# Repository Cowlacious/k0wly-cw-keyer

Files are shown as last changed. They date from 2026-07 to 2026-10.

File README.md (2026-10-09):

# K0WLY Two-Way CW Keyer






A full-featured two-way CW (Morse code) keyer built on the LilyGO T-Display S3 AMOLED board, featuring peer-to-peer WiFi communication via ESP-NOW, real-time Morse decoding, and a beautiful 1.91" AMOLED display.

**Designed and built by K0WLY — Saratoga Springs, Utah — Grid DN40**

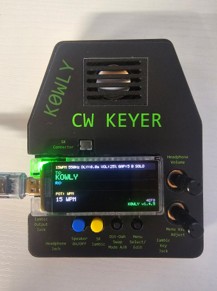
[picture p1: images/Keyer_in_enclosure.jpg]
K0WLY CW Keyer — Top View
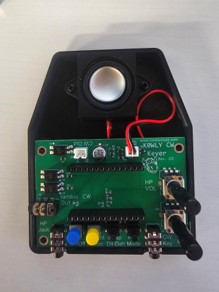
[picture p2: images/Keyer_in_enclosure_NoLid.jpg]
K0WLY CW Keyer — System View
  
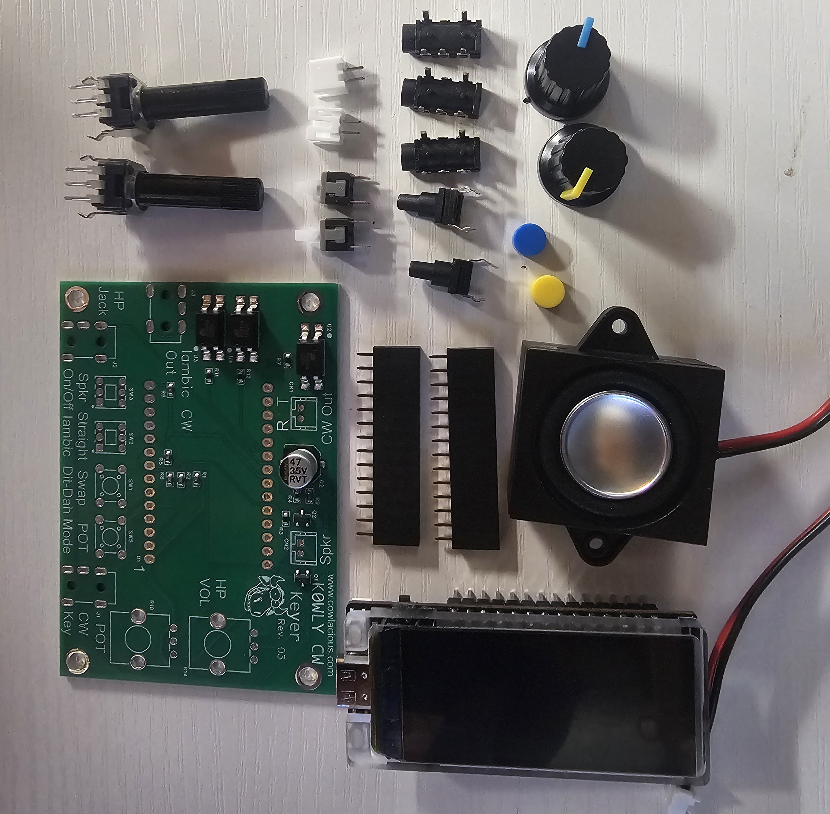
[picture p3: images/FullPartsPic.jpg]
K0WLY CW Keyer — Parts View


---

## Features

- **Iambic Mode A, Iambic Mode B and Ultimatic keyer modes** with adjustable speed (5–40 WPM)
- **Straight key mode** selectable via hardware switch
- **Adjustable sidetone frequency** (400–900 Hz) — each unit independent
- **Logarithmic volume control** via PWM, works for speaker and headphones
- **Head copy delay** (0–3 seconds) for incoming character display
- **WiFi file playback** — upload .txt practice files from any phone browser, plays as CW
- **WiFi Access Point** — unique hotspot per unit (K0WLY-XXXX), no password, works on all platforms
- **Iambic DIT/DAH output** (GPIO40/41) — connect to radio paddle input for radios with built-in keyers (e.g. Xiegu G90)
- **Web interface** — dit/dah swap, file management, all from phone browser at 192.168.4.1
- **Automatic peer-to-peer WiFi pairing** via ESP-NOW — no router needed
- **Two-way CW communication** — transmit and receive simultaneously
- **Real-time Morse decoding** — letters, numbers, punctuation, and prosigns
- **Scrolling TX/RX display** on 1.91" AMOLED (536×240)
- **Farnsworth spacing** — two-speed CW for learning (character speed plus a 4 WPM-or-higher overall speed, e.g. 20/10)
- **Adjustable word gap spacing** (off or 4–9 dits) for display readability
- **Non-volatile settings** — survives power cycles
- **Single pot** with mode cycling for all parameter adjustments
- **Frame buffer display** — instantaneous screen updates, no glitch

---

## Hardware

### Bill of Materials

| Component | Value | Notes |
|---|---|---|
| MCU Board | LilyGO T-Display S3 AMOLED | ESP32-S3R8, 1.91" AMOLED |
| Optocoupler | PC817 | Radio key line isolation |
| Transistors | 2N4401 × 2 | Speaker + headphone audio |
| Base resistors | 470Ω × 2 | GPIO13 to transistor bases |
| Pull-up resistors | 10kΩ × 2 | DIT/DAH paddle inputs |
| Key mode resistor | 100kΩ | GPIO15 pull-up |
| Headphone pull-up | 1kΩ | Headphone transistor collector |
| Coupling cap | 47µF bi-polar | Headphone output only |
| Headphone resistor | 100Ω | Series protection |
| Pot | 10–20kΩ linear | Parameter adjustment |
| Speaker | 8Ω | Direct connection, no cap needed |
| 3.5mm jack | TRS | Headphone output |

### GPIO Pin Assignments

| Function | GPIO | Notes |
|---|---|---|
| DIT Paddle | GPIO11 | Active LOW, ext 10kΩ pull-up |
| DAH Paddle | GPIO10 | Active LOW, ext 10kΩ pull-up |
| Key Out | GPIO12 | HIGH=keyed, drives PC817 |
| Sidetone | GPIO13 | PWM → 470Ω → 2N4401 |
| Pot (ADC) | GPIO14 | Wiper of 10–20kΩ pot |
| Key Mode | GPIO15 | SPST: open=iambic, GND=straight key |
| Paddle Reverse | GPIO16 | PBNO momentary button — short press swaps dit/dah, long press (1 sec) cycles keyer mode A → B → U (Ultimatic) |
| Pot Mode Select | GPIO39 | PBNO momentary button |

### Audio Circuit Notes

**Speaker circuit** — direct connection, no coupling capacitor:
```
3.3V ──── Speaker ──── Collector
                           │
GPIO13 ── 470Ω ── Base  2N4401 #1
                           │
                       Emitter ──── GND
```

**Headphone circuit** — separate transistor with coupling cap:
```
3.3V ──── 1kΩ ──── Collector
                       │
                   +47µF- ──── 100Ω ──── 3.5mm tip
                       │                 3.5mm sleeve ──── GND
GPIO13 ── 470Ω ── Base  2N4401 #2
                           │
                       Emitter ──── GND
```

> **Note:** The speaker connects directly without a coupling capacitor. A coupling cap in series with the speaker will block all audio. The headphone output uses a separate transistor with its own 3.3V pull-up and a 47µF bi-polar coupling cap to block DC.

---

## Firmware

### Requirements

- [PlatformIO](https://platformio.org/) with VS Code
- ESP32 Arduino framework 2.0.x

### platformio.ini

This is the project's `firmware/platformio.ini`. It uses the custom board definition in `firmware/boards/` and the partition table in `firmware/partitions.csv`.

```ini
[platformio]
boards_dir = ./boards

[env:t_display_s3_amoled]
platform = espressif32
board = lilygo-t-amoled
framework = arduino
monitor_speed = 115200
board_build.partitions = partitions.csv
board_build.filesystem = littlefs
build_flags =
    -DBOARD_HAS_PSRAM
    -DARDUINO_USB_CDC_ON_BOOT=1
    -DASYNCWEBSERVER_REGEX=0
lib_deps =
    https://github.com/Xinyuan-LilyGO/LilyGo-AMOLED-Series
    https://github.com/moononournation/Arduino_GFX#v1.4.7
    https://github.com/ESP32Async/AsyncTCP
    https://github.com/ESP32Async/ESPAsyncWebServer
```

### Building and Flashing

1. Clone this repository
2. Open the `firmware/` folder in VS Code with PlatformIO
3. Connect the T-Display S3 AMOLED via USB
4. Hold BOOT button, plug in USB, release BOOT
5. Click Upload in PlatformIO

---

## Operation

### Display Layout

```
┌─────────────────────────────────────────────────────────────────────┐
│ K0WLY   20WPM  700Hz  DLY:0.0s  VOL:50%       IAM  SOLO           │  ← Header
├─────────────────────────────────────────────────────────────────────┤
│ TX> CQ CQ CQ DE K0WLY K0WLY K                                      │  ← Outgoing (green)
├─────────────────────────────────────────────────────────────────────┤
│ RX> TNX FER CALL OM 73 DE                                           │  ← Incoming (cyan)
├─────────────────────────────────────────────────────────────────────┤
│ POT: WPM                                                            │
│ 20 WPM                                                              │  ← Status area
│ SEARCHING...                                                        │
└─────────────────────────────────────────────────────────────────────┘
```

### Parameter Adjustment

| Button Action | Result |
|---|---|
| Short press | Cycle to next parameter: WPM → FREQ → DELAY → VOL |
| Long press (1 sec) | Enter/exit edit mode for current parameter |
| Turn pot (in edit) | Adjust value — saves to flash in real time |

### Two-Way Operation

1. Power on both units — they auto-discover each other via ESP-NOW
2. Header changes from **SOLO** to **DUAL** when paired
3. Each unit hears all CW at its own sidetone frequency
4. Incoming decoded characters appear on the RX line (cyan)
5. Head copy delay (0–3s) lets you practice mental decoding

### Morse Code Coverage

Letters A–Z, numbers 0–9, punctuation (. , ? / ( ) : ; - ' " @ & ! _),
and prosigns: **+** = AR, **=** = BT, **~** = SK

---

## CW Timing Standard

**PARIS standard (ITU-R M.1677-1)**

| Element | Duration |
|---|---|
| Dit | 1 × (1200/WPM) ms |
| Dah | 3 × (1200/WPM) ms |
| Inter-element gap | 1 × (1200/WPM) ms |
| Character gap | 3 × (1200/WPM) ms |
| Word gap | 7 × (1200/WPM) ms |

---

## Updating Firmware

Each GitHub release includes a pre-compiled `firmware.bin` file that can be flashed without installing PlatformIO or compiling any code.

### Option 1 — Espressif Flash Download Tool (Windows, easiest)

1. Download the **[Espressif Flash Download Tool](https://www.espressif.com/en/support/download/other-tools)** — look for "Flash Download Tools" and download the `.zip`
2. Extract and run `flash_download_tool.exe`
3. Select **ESP32-S3** as the chip type
4. Click the `...` button next to the first address field and select your `firmware.bin`
5. Set the address to `0x10000`
6. Select your COM port from the dropdown (check Device Manager if unsure)
7. Set baud rate to `921600`
8. Click **START**
9. If it fails to connect, hold the **BOOT** button on the board, press and release **RST**, then release **BOOT** and click START again

### Option 2 — esptool.py (Windows / Mac / Linux)

**Install esptool** (requires Python):
```
pip install esptool
```

**Flash the firmware:**
```
esptool.py --port COM3 --baud 921600 write_flash 0x10000 firmware.bin
```

Replace `COM3` with your actual port:
- **Windows** — check Device Manager under Ports (COM & LPT)
- **Mac** — typically `/dev/tty.usbmodem101` or `/dev/cu.usbmodem101`
- **Linux** — typically `/dev/ttyACM0`

If connection fails, hold **BOOT**, press **RST**, release **BOOT**, then run the command.

### Building from Source

For developers who want to modify the firmware:
- Install [VS Code](https://code.visualstudio.com/) and the [PlatformIO extension](https://platformio.org/)
- Clone this repository
- Open `firmware/` folder in VS Code
- The `lilygo-t-amoled` board definition (`firmware/boards/lilygo-t-amoled.json`) and partition table (`firmware/partitions.csv`) are already included
- Build and upload using PlatformIO

---
## Repository Structure

```
k0wly-cw-keyer/
├── firmware/          # PlatformIO project
│   ├── src/
│   │   └── main.cpp
│   ├── boards/        # lilygo-t-amoled board definition
│   ├── partitions.csv
│   └── platformio.ini
├── hardware/
│   ├── schematic/     # Schematic PDFs and BOMs
│   ├── pcb/           # Gerbers and pick-and-place files
│   └── enclosure/     # Enclosure 3D models (SolidWorks and STL)
├── docs/              # Operator's Manual (DOCX and PDF) and User Guide (DOCX)
├── images/            # Photos and screenshots
├── LICENSE            # CERN-OHL-W v2 (hardware + firmware)
├── LICENSE-DOCS       # CC BY 4.0 (documentation)
├── NOTICE             # Required attribution notice
├── CONTRIBUTING.md
├── CHANGELOG.md
└── README.md
```

---

## License

**Hardware and Firmware:** Licensed under the
[CERN Open Hardware Licence Version 2 - Weakly Reciprocal (CERN-OHL-W v2)](LICENSE).

**Documentation:** Licensed under
[Creative Commons Attribution 4.0 International (CC BY 4.0)](LICENSE-DOCS).

Copyright © 2026 K0WLY (Carl Cowley) — Saratoga Springs, Utah

Attribution to **K0WLY** must be retained on all copies and derivatives.

---

## Contributing

See [CONTRIBUTING.md](CONTRIBUTING.md) for guidelines.

## Changelog

See [CHANGELOG.md](CHANGELOG.md) for version history.

---

*73 de K0WLY — dit dit*

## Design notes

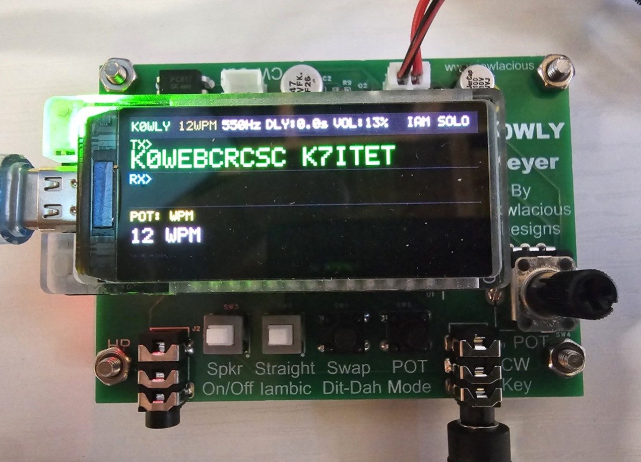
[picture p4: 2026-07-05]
images/keyer_top.jpg

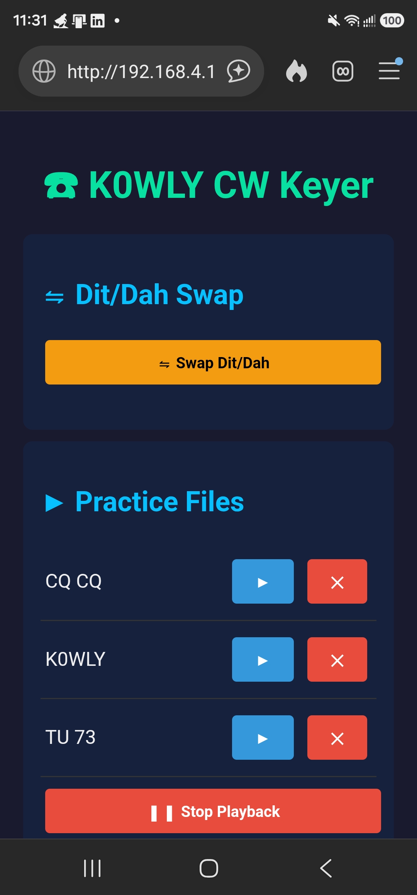
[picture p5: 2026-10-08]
images/Screenshot1_WebPage.jpg

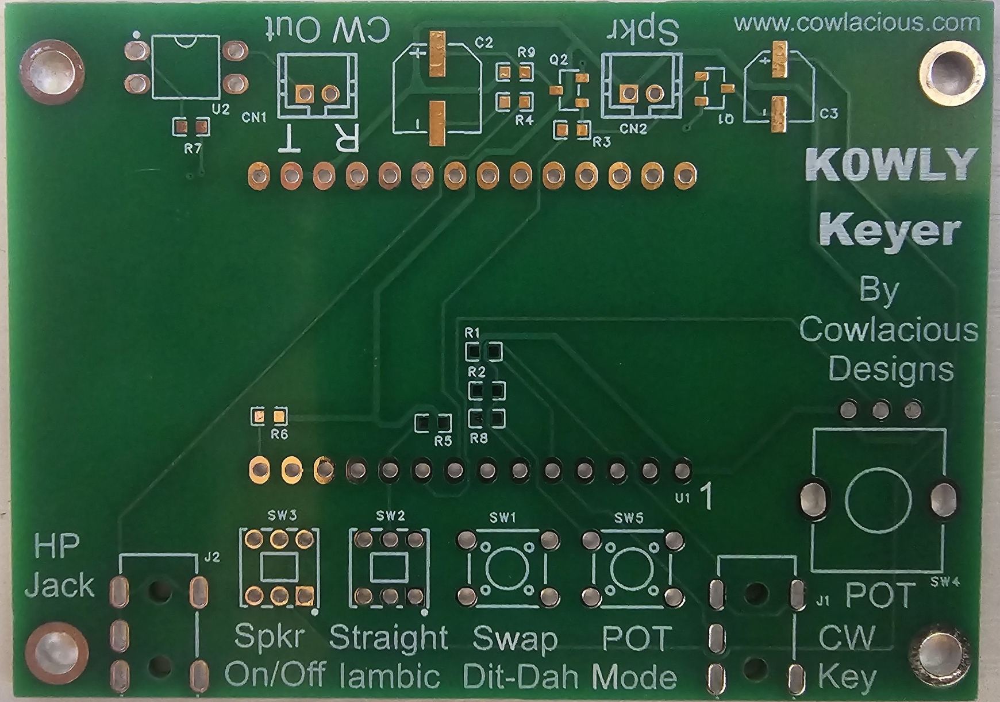
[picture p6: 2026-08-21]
images/Keyer_PCB.jpg

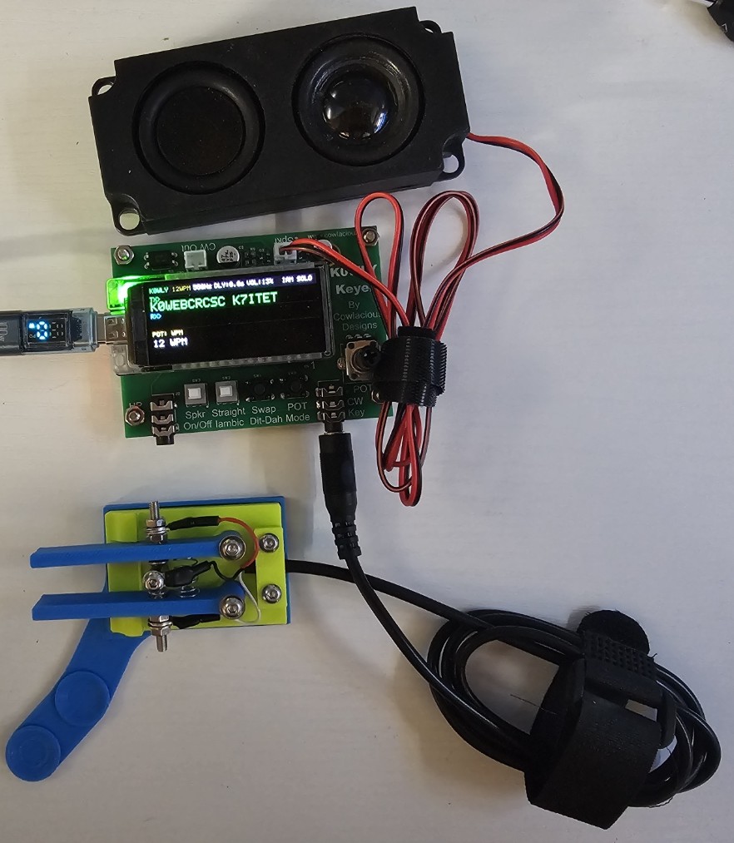
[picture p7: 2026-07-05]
images/keyer_system.jpg

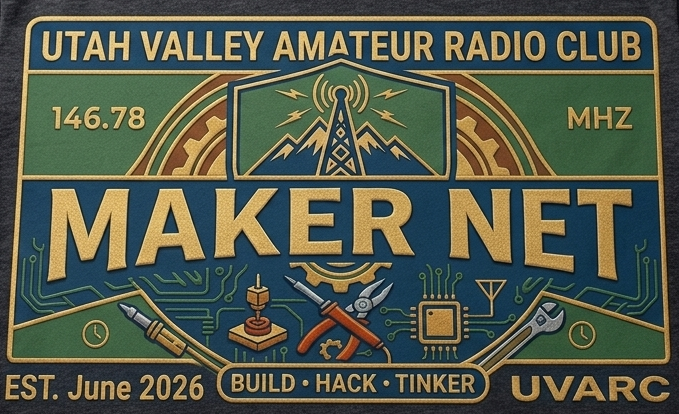
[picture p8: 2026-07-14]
images/Gemini_Generated_Image_x44wqgx44wqgx44w (1).png

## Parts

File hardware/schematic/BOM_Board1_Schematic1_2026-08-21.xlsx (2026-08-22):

No. | Quantity | Comment | Designator | Footprint | Value | Manufacturer Part | Manufacturer | Supplier Part | Supplier
1 | 1 | 47uF | C2 | CAP-SMD_BD6.3-L6.6-W6.6-FD | 47uF | RVT1V470M0605 | ROQANG(容强) | C72522 | LCSC
2 | 2 | PH-2A | CN1,CN2 | CONN-TH_PH-2A_C53055425 |  | PH-2A | LXWCONN(连兴旺电子) | C53055425 | LCSC
3 | 3 | 313耳机座直插 | J1,J2,J3 | AUDIO-TH_PJ313D |  | 313耳机座直插 | BOOMELE(博穆精密) | C18167 | LCSC
4 | 2 | MMBT4401LT1G | Q1,Q2 | SOT-23-3_L2.9-W1.3-P1.90-LS2.4-BR |  | MMBT4401LT1G | onsemi(安森美) | C31776 | LCSC
5 | 5 | 10kΩ | R1,R2,R5,R6,R8 | R0603 | 10kΩ | AC0603FR-0710KL | YAGEO(国巨) | C116677 | LCSC
6 | 4 | 470Ω | R3,R7,R11,R12 | R0603 | 470Ω | CRCW0603470RFKEA | VISHAY(威世) | C844786 | LCSC
7 | 1 | 100Ω | R4 | R0603 | 100Ω | CRCW0603100RFKEAHP | VISHAY(威世) | C844725 | LCSC
8 | 1 | 1kΩ | R9 | R0603 | 1kΩ | FRC0603F1001TS | FOJAN(富捷) | C2907002 | LCSC
9 | 1 | 10kΩ | R10 | RES-TH_RK09K1130AAU | 10kΩ | RK09K1130081 | ALPSALPINE(阿尔卑斯阿尔派) | C470311 | LCSC
10 | 2 | TC-00104FB-110E-03 | SW1,SW5 | SW-TH_4P-L6.0-W6.0-P4.50-LS6.5 |  | TC-00104FB-110E-03 | HOOYA(皓宇电子) | C7542981 | LCSC
11 | 2 | 5.8 ZSGT | SW2,SW3 | SW-TH_5.8ZSGT |  | 5.8 ZSGT | SHOU HAN(首韩) | C2681587 | LCSC
12 | 1 | Lilygo T-Display T3 | U1 | LilygoT-DisplayS3
13 | 3 | PC817A | U2,U3,U4 | DIP-4_L4.6-W6.5-P2.54-LS7.6-BL |  | PC817A | AOTE(奥特) | C42371498 | LCSC

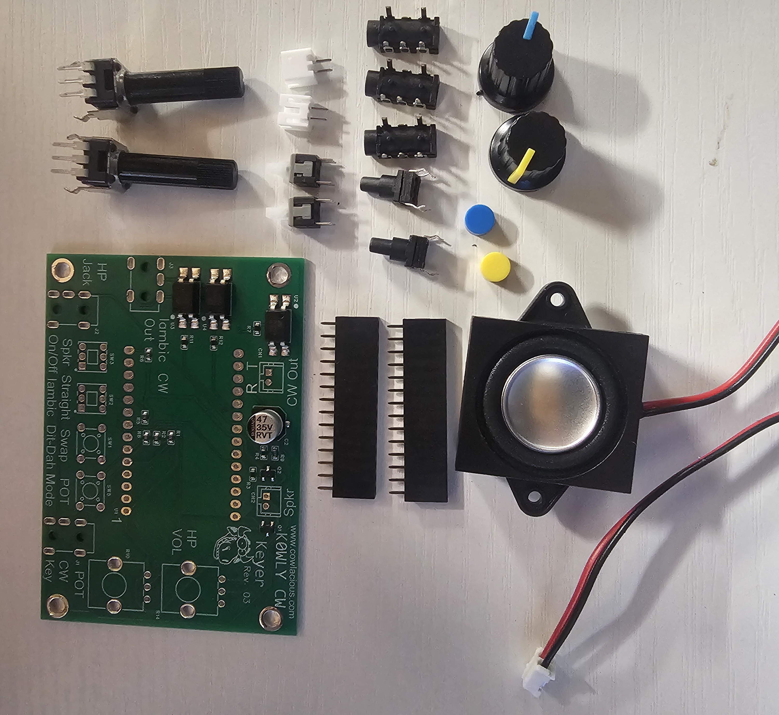
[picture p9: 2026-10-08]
images/PartsPic.jpg

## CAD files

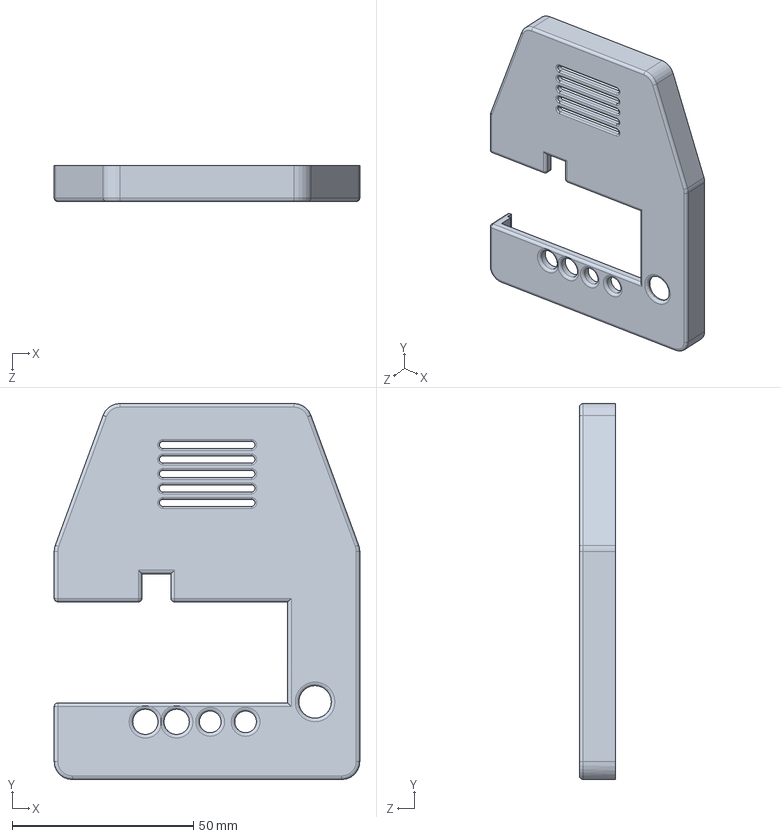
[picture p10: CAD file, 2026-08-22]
hardware/enclosure/EnclosureTop.SLDPRT
84.4 x 103.8 x 10.0 mm

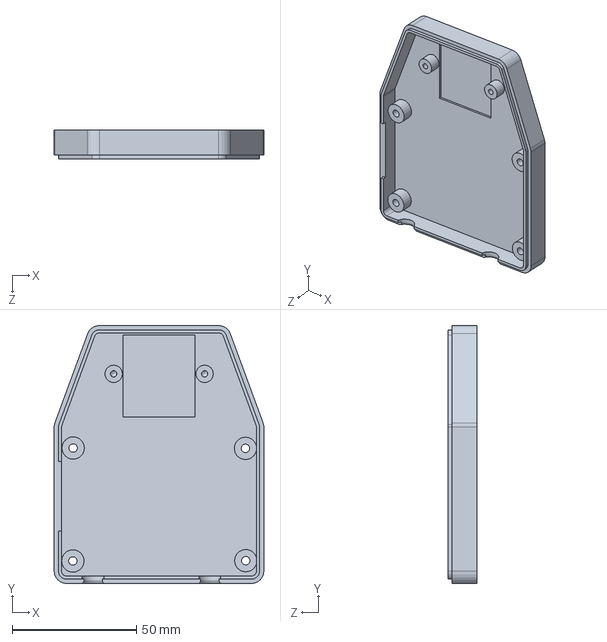
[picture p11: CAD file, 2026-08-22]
hardware/enclosure/EnclosureBottom.SLDPRT
84.4 x 103.8 x 11.5 mm

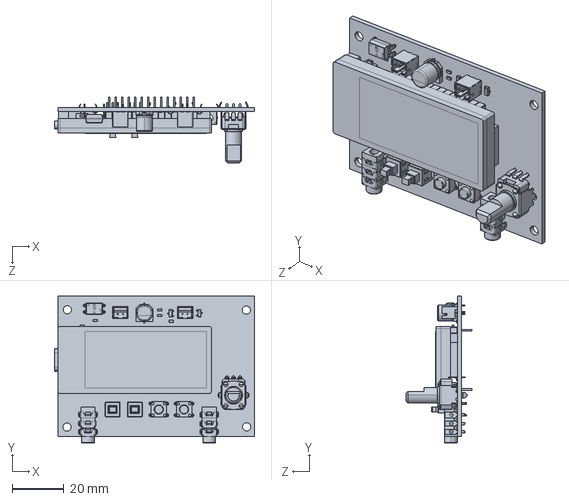
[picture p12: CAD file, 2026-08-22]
hardware/enclosure/3D_PCB1_2026-08-07.SLDPRT
77.5 x 56.9 x 25.7 mm

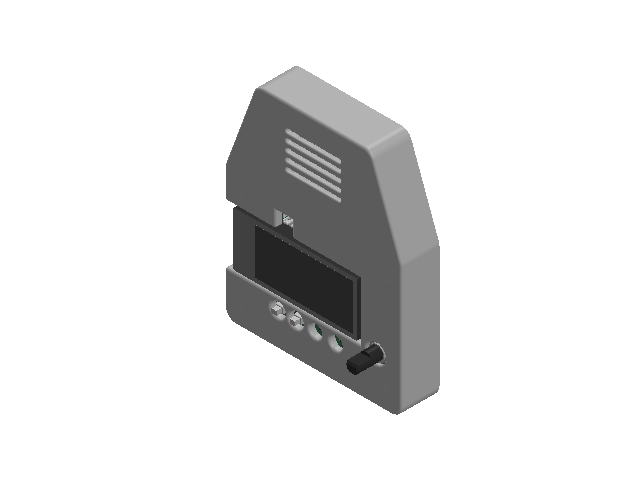
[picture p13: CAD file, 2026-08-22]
hardware/enclosure/Keyer_Enclosure.SLDASM
3D_PCB1_2026-08-07
EnclosureBottom
EnclosureTop
B18.6.7M - M3 x 0.5 x 16 Type I Cross Recessed PHMS --16N x 4
3128_speaker.step

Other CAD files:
hardware/enclosure/EnclosureBottom.STL
hardware/enclosure/EnclosureTop.STL

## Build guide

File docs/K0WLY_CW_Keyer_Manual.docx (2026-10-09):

K0WLY Two-Way CW Keyer

LilyGO T-Display S3 AMOLED

Operator's Manual — Preliminary

Version 1.5.0

K0WLY — Saratoga Springs, Utah — Grid DN40

License

Copyright © 2026 K0WLY (Carl Cowley) — CERN-OHL-W v2 / CC BY 4.0

73 de K0WLY

# 1. Overview

The K0WLY Two-Way CW Keyer is an ESP32-S3 based iambic keyer on the LilyGO T-Display S3 AMOLED (v1.5.0).

- Iambic Mode A, Iambic Mode B or Ultimatic keyer, 5–40 WPM, straight key mode
- Farnsworth spacing — character speed plus overall (effective) speed, e.g. 20/10
- Key output via PC817 optocoupler (GPIO12)
- Iambic DIT/DAH output (GPIO40/41) for radios with built-in keyers
- Paddle reverse and keyer mode (A/B/Ultimatic) via GPIO16
- Adjustable sidetone 400–900 Hz, logarithmic volume
- Head copy delay 0–3s or Audio Only mode
- Word gap spacing (off or 4–9 dits)
- WiFi AP (K0WLY-XXXX) with web interface for file management
- Text file playback with pause/resume, drives iambic output
- Automatic ESP-NOW peer-to-peer pairing, two-way CW
- Full Morse decoding: A–Z, 0–9, punctuation, prosigns

# 2. Display Layout

Zone | Location | Content
Header Bar | Top 32px | WPM, Hz, DLY, VOL, GAP, A/B/U/SK, SOLO/DUAL
TX Line | Upper middle | Outgoing chars (green)
RX Line | Lower middle | Incoming chars (cyan)
Status Area | Bottom 96px | Pot mode, value, peer MAC, unit ID, version

## 2.1 Header Bar

- WPM or WPM/FARN — character speed / overall (effective) speed
- Hz — sidetone frequency
- DLY — head copy delay or AO
- VOL — volume percentage
- GAP — word gap setting
- A / B / U / SK — Iambic Mode A, Iambic Mode B, Ultimatic, or Straight Key
- SOLO / DUAL — ESP-NOW peer status

# 3. Controls and Connections

## 3.1 GPIO Pin Assignments

Function | GPIO | Notes
DIT Paddle Input | GPIO11 | Active LOW, ext 10kΩ pull-up
DAH Paddle Input | GPIO10 | Active LOW, ext 10kΩ pull-up
Key Out | GPIO12 | HIGH=keyed, PC817 optocoupler
Sidetone | GPIO13 | PWM → 470Ω → 2N4401 → speaker/headphones
Pot (ADC) | GPIO14 | Wiper of 10–20kΩ pot
Key Mode | GPIO15 | SPST: open=iambic, closed=straight key
Paddle Reverse / Keyer Mode | GPIO16 | Short=dit/dah swap, Long=cycle Mode A/B/U
Pot Mode Select | GPIO39 | PBNO: short=cycle, long=edit
Iambic DIT Out | GPIO40 | Active HIGH, PC817 optocoupler to radio DIT
Iambic DAH Out | GPIO41 | Active HIGH, PC817 optocoupler to radio DAH

## 3.2 GPIO16 Button Functions

Press | Action
Short press | Toggles dit/dah swap (also available on web page)
Long press (1 sec) | Cycles keyer mode A → B → U (Ultimatic) → A — header shows A, B or U

## 3.3 Keyer Modes

Mode A (default) — when both paddles are released during an element, the keyer finishes that element and stops.

Mode B — when both paddles are released during an element, the keyer sends one additional opposite element before stopping. Preferred by some operators for smoother squeeze keying.

Ultimatic (U) — when both paddles are squeezed, the paddle pressed most recently wins and repeats instead of alternating. Release it and the keyer goes to the paddle still held, or stops if none is. A new tap of the opposite paddle during an element is remembered and sent next. A paddle that is simply held down is not remembered, so letting go of both paddles stops the keyer after the current element.

NOTE: Keyer mode (A/B/U) is saved to flash and restored on power cycle.

## 3.4 Key Output (GPIO12)

Drives a PC817 optocoupler to key the transceiver. Active HIGH. Never connect GPIO12 directly to a radio.

## 3.5 Iambic DIT/DAH Output (GPIO40/41)

For radios with built-in keyers. Active HIGH (GPIO HIGH = LED on = radio keyed). Both outputs driven during file playback. Paddle reverse applies to outputs.

- Tip = DIT (GPIO40 optocoupler)
- Ring = DAH (GPIO41 optocoupler)
- Sleeve = GND

NOTE: Set the radio's WPM to match the keyer's CHARACTER speed. Farnsworth gaps are transparent to the radio.

## 3.6 Audio Circuit

Speaker — direct, NO coupling capacitor:

3.3V → Speaker → Collector / 2N4401 / GPIO13 → 470Ω → Base / Emitter → GND

Headphone — with coupling cap:

3.3V → 1kΩ → Collector / 2N4401 #2 / Emitter → GND. Collector → 10kΩ volume pot → 47µF bi-polar → 100Ω → 3.5mm tip.

# 4. Parameter Adjustment

## 4.1 Pot Mode Button

Press | Action
Short press | Cycle: WPM → FREQ → DELAY → VOL → GAP → WPM
Long press (1s) | Enter/exit edit mode
Short press (in edit) | Exit edit and advance to the next parameter (in WPM, the first short press moves to the Farnsworth step). Values save as you adjust

## 4.2 Parameter Ranges

Parameter | Range | Notes
Char Speed | 5–40 WPM | PARIS standard
Farnsworth | 4 WPM – char speed | Overall (effective) speed
Frequency | 400–900 Hz | Each unit independent
Head Copy Delay | 0.0–3.0s or AO | Top 10% = Audio Only
Volume | 2–100% | Logarithmic
Word Gap | OFF or 4–9 dits | Bottom 20% = OFF

# 5. WiFi Operation

## 5.1 Access Point

Each unit creates K0WLY-XXXX (XXXX = last 4 hex of MAC). No password. Browse to http://192.168.4.1.

## 5.2 Web Interface

- Dit/Dah Swap button (orange)
- Practice Files — Play (▶) and Delete (✕) per file
- Stop Playback — immediate
- Pause/Resume — resumes from same position
- Upload Text File — .txt files only

## 5.3 Text File Playback

- TX line clears on start, characters appear as they sound
- A newline counts as one word gap; blank lines and a newline right after a space add nothing extra. Spaces you type are always kept
- KEY OUT and iambic outputs driven during playback
- Elements transmitted to peer over ESP-NOW

## 5.4 ESP-NOW Peer

Units auto-discover on channel 1. Header shows DUAL (green) when paired.

# 6. Firmware Information

Item | Details
Platform | ESP32-S3 (LilyGO T-Display S3 AMOLED)
Framework | Arduino via PlatformIO
Board Definition | lilygo-t-amoled (custom boards/ folder)
WiFi | AP+STA: ESPAsyncWebServer + ESP-NOW
File Storage | LittleFS on internal flash
Keyer Task | FreeRTOS Core 1, 1ms resolution
Keyer Modes | Mode A, Mode B and Ultimatic (GPIO16 long press)
NVS Version | 4
CW Standard | PARIS (ITU-R M.1677-1)
License | CERN-OHL-W v2 / CC BY 4.0

# 7. Default Settings

Setting | Default
Speed | 20 WPM
Farnsworth | Off
Sidetone Frequency | 700 Hz
Head Copy Delay | 0.0 seconds
Volume | 64%
Word Gap | OFF
Keyer Mode | Mode A
Paddle Reverse | Normal
AP SSID | K0WLY-XXXX (unique per unit)

# 8. Troubleshooting

Symptom | Likely Cause | Fix
Display blank on boot | Crash | Hold BOOT, press RST, reflash
Always SOLO | Peer out of range | Both units on channel 1
Wrong characters | Paddles reversed | Short press GPIO16 or web swap
No sidetone | Volume at min | Enter VOL edit, increase
No speaker audio | Coupling cap installed | Remove cap
Radio not keying | Optocoupler issue | Check GPIO12 circuit
G90 wrong speed | G90 WPM mismatch | Set G90 WPM = char speed
K0WLY-XXXX not visible | AP not started | Check serial monitor
Files not showing | LittleFS issue | Reflash with correct board

# Morse Code Reference

Letters:

A ·− | B −··· | C −·−· | D −·· | E · | F ··−·
G −−· | H ···· | I ·· | J ·−−− | K −·− | L ·−··
M −− | N −· | O −−− | P ·−−· | Q −−·− | R ·−·
S ··· | T − | U ··− | V ···− | W ·−− | X −··−
Y −·−− | Z −−··

Numbers:

0 −−−−− | 1 ·−−−− | 2 ··−−− | 3 ···−− | 4 ····− | 5 ·····
6 −···· | 7 −−··· | 8 −−−·· | 9 −−−−·

Punctuation:

. period ·−·−·− | , comma −−··−− | ? question ··−−·· | / slash −··−· | ( open −·−−· | ) close −·−−·−
: colon −−−··· | ; semi −·−·−· | - hyphen −····− | ' apos ·−−−−· | " quote ·−··−· | @ at ·−−·−·
& amp ·−··· | ! excl −·−·−− | _ under ··−−·− | $ dollar ···−··−

Prosigns:

+ AR ·−·−· end msg | = BT −···− break | ~ SK ···−·− end QSO | & AS ·−··· wait

K0WLY Two-Way CW Keyer — Preliminary Manual v1.5.0 — 73 de K0WLY

K0WLY Two-Way CW Keyer — Preliminary Manual v1.5.0 — Copyright © 2026 K0WLY — CERN-OHL-W v2 / CC BY 4.0

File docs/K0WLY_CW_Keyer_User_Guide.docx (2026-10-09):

K0WLY Two-Way CW Keyer

User Guide

Version 1.5.0

K0WLY — Saratoga Springs, Utah — Grid DN40

# 1. What Is the K0WLY CW Keyer?

The K0WLY Two-Way CW Keyer is a Morse code practice and operating tool. Connect your iambic paddle and get:

- Sidetone speaker — hear what you send
- Scrolling display showing characters you send and receive
- Two-way practice — connect two units wirelessly
- Text file playback — load practice files from your phone
- Radio keying output — connect to your transceiver
- Iambic Mode A, Iambic Mode B or Ultimatic — selectable via long press

# 2. Understanding the Display

Area | What It Shows
Header (top) | Speed, frequency, delay, volume, gap, mode, peer status
TX line (green) | Characters you send or play from file
RX line (cyan) | Characters received from other unit
Status area (bottom) | Current setting, peer info, unit ID and version

## 2.1 Header Bar

- WPM or WPM/FARN — sending speed
- Hz — sidetone pitch
- DLY — head copy delay (0.0s = off, AO = Audio Only)
- VOL — volume
- GAP — word gap (OFF or 4–9)
- A / B / U / SK — Iambic Mode A, Iambic Mode B, Ultimatic, or Straight Key
- SOLO / DUAL — whether a second unit is connected

# 3. Controls

## 3.1 Knob and Mode Button

Action | Result
Short press | Cycle: WPM → FREQ → DELAY → VOL → GAP → WPM
Long press (1s) | Enter or exit edit mode — [EDIT] appears
Turn knob (in edit) | Adjust value
Short press (in edit) | Exit edit mode and move to the next setting. Values save as you turn the knob

## 3.2 Paddle Reverse Button

Press | Action
Short press | Toggle dit/dah swap
Long press (1s) | Cycle keyer mode A → B → U (Ultimatic) → A — header shows A, B or U

## 3.3 Keyer Modes

Mode A — keyer stops after the current element when both paddles are released. Most common mode.

Mode B — keyer sends one extra opposite element after both paddles are released. Some operators prefer this for smoother squeeze keying.

Ultimatic (U) — when both paddles are squeezed, the last paddle pressed wins and repeats instead of alternating. Let go of it and the keyer goes to the paddle still held, or stops if none is. A quick tap of the other paddle during an element is remembered, but a paddle you are just holding down is not, so letting go of both stops the keyer.

TIP: Keyer mode (A/B/U) is saved and restored on power cycle.

## 3.4 Setting WPM and Farnsworth

- Long press WPM — set character speed
- Short press — set overall (effective) speed (4 WPM min, up to char speed). At 20/10, characters are sent at 20 WPM and the spacing is stretched so the overall speed is 10 WPM
- Short press — exit. Header shows 25WPM or 25/10

TIP: When using the iambic output to a radio with a built-in keyer, always set the radio's WPM to match your CHARACTER speed (first number). Farnsworth gaps are transparent to the radio and work correctly at any Farnsworth setting.

# 4. Using Your Phone

## 4.1 Connecting

- Connect to WiFi network K0WLY-XXXX (XXXX matches unit ID on display)
- No password required — tap Connect Anyway if warned about no internet
- Open browser — go to http://192.168.4.1

## 4.2 Web Page

Dit/Dah Swap (orange)

Same as the hardware paddle reverse button.

Practice Files

- Tap ▶ to play a file
- Tap ✕ to delete a file
- File names show without .txt, underscores as spaces

Stop / Pause / Resume

- Stop Playback — immediate stop, clears buffer
- Pause/Resume — instant pause, resumes from same position

Upload Text File

Select any .txt file from your phone and tap Upload.

## 4.3 Practice File Tips

- Use plain text files (.txt)
- Spaces between words become CW word gaps
- A new line counts as one word gap; blank lines add no extra pause. Spaces you type are always kept
- Name files descriptively: cq_de_k0wly.txt → shows as 'cq de k0wly'
- All punctuation and prosigns are supported

# 5. Two-Way CW Practice

Two units auto-discover each other and show DUAL in green. No setup needed.

- TX line (green) — what you send
- RX line (cyan) — what the other station sends
- Each unit plays at its own sidetone pitch
- Head copy delay applies to incoming display only — audio always immediate

## 5.1 Head Copy Delay

- 0.0s — normal, characters appear immediately
- 0.5s–3.0s — try to copy before looking
- AO (Audio Only) — characters never appear, pure audio copy

# 6. Connecting to a Transceiver

## 6.1 Key Output

Connects to your radio's straight key input. Keyer controls exact timing.

## 6.2 Iambic Output

For radios with built-in keyers (e.g. Xiegu G90). 3.5mm stereo jack:

- Tip — DIT
- Ring — DAH
- Sleeve — GND

NOTE: Set the radio's WPM to match the keyer's character speed. With Farnsworth (e.g. 25/10) set the radio to 25 WPM. This applies to all radios with built-in keyers.

# 7. Default Settings

Setting | Default
Speed | 20 WPM
Farnsworth | Off
Sidetone Frequency | 700 Hz
Head Copy Delay | 0.0 seconds
Volume | 64%
Word Gap | OFF
Keyer Mode | Mode A
Paddle Reverse | Normal

# 8. Updating Firmware

## 8.1 Windows — Espressif Flash Download Tool

- Download from espressif.com/en/support/download/other-tools
- Select ESP32-S3, browse to firmware.bin, set address 0x10000
- Select COM port, baud 921600, click START
- If fails: hold BOOT, press RST, release BOOT, click START

## 8.2 Mac/Linux — esptool.py

pip install esptool

esptool.py --port /dev/tty.usbmodem101 --baud 921600 write_flash 0x10000 firmware.bin

# 9. Practice Tips

- Start at comfortable speed — accuracy beats speed
- Use Farnsworth — char speed 20-25 WPM, effective 5-10 WPM
- Increase head copy delay gradually toward Audio Only
- Practice with real QSO text, call signs, contest exchanges
- Try Iambic Mode A, Mode B and Ultimatic — find which feels most natural
- Two-unit practice is the closest thing to a real QSO

# 10. Quick Reference

Task | How
Change speed | Short press → WPM → long press → turn → short press
Set Farnsworth | Long press WPM → char speed → short press → overall speed → short press
Swap dit/dah | Short press paddle reverse button OR web page
Change keyer mode (A/B/U) | Long press paddle reverse button
Connect phone | WiFi → K0WLY-XXXX → browser → 192.168.4.1
Play a file | Web page → ▶ next to file name
Pause playback | Web page → Pause/Resume
Stop playback | Web page → Stop Playback
Audio Only mode | Short press → DELAY → long press → turn to max → short press

# Morse Code Reference

Letters:

A ·− | B −··· | C −·−· | D −·· | E · | F ··−·
G −−· | H ···· | I ·· | J ·−−− | K −·− | L ·−··
M −− | N −· | O −−− | P ·−−· | Q −−·− | R ·−·
S ··· | T − | U ··− | V ···− | W ·−− | X −··−
Y −·−− | Z −−··

Numbers:

0 −−−−− | 1 ·−−−− | 2 ··−−− | 3 ···−− | 4 ····− | 5 ·····
6 −···· | 7 −−··· | 8 −−−·· | 9 −−−−·

Punctuation:

. period ·−·−·− | , comma −−··−− | ? question ··−−·· | / slash −··−· | ( open −·−−· | ) close −·−−·−
: colon −−−··· | ; semi −·−·−· | - hyphen −····− | ' apos ·−−−−· | " quote ·−··−· | @ at ·−−·−·
& amp ·−··· | ! excl −·−·−− | _ under ··−−·− | $ dollar ···−··−

Prosigns:

+ AR ·−·−· end msg | = BT −···− break | ~ SK ···−·− end QSO | & AS ·−··· wait

K0WLY Two-Way CW Keyer — User Guide v1.5.0 — 73 de K0WLY

K0WLY Two-Way CW Keyer — User Guide v1.5.0 — Copyright © 2026 K0WLY — CERN-OHL-W v2 / CC BY 4.0

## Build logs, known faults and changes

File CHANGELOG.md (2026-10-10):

# Changelog

All notable changes to the K0WLY Two-Way CW Keyer are documented here.

Format follows [Keep a Changelog](https://keepachangelog.com/en/1.0.0/).

---

## [1.5.0] — 2026 — Ultimatic Keyer Mode

Adds an Ultimatic mode, contributed by UtahDave (W7OM) in
[PR #9](https://github.com/Cowlacious/k0wly-cw-keyer/pull/9) and merged onto
v1.4.10, with one change to how held paddles are remembered. Modes A and B
are unchanged. Tested on a host simulation and on a LilyGO unit by K0WLY (mode cycling,
squeeze priority, tap memory, release behavior).

### Added
- **Ultimatic keyer mode** — when both paddles are squeezed, the paddle pressed
  most recently takes over and repeats (no alternation). Releasing it returns to
  the paddle still held, or stops if none is. A new tap of the opposite paddle
  during an element is remembered and sent next. A paddle that is merely held
  down is not remembered, so letting go of both paddles stops the keyer after
  the current element (the letter A sends as A, not R). Source:
  [morsecode.world](https://morsecode.world/iambic.html).
  - GPIO16 long press now cycles A → B → U (Ultimatic) → A
  - Header shows A, B or U after the GAP setting

### Changed
- Keyer mode is stored in NVS as `kmode` (0=A, 1=B, 2=U) instead of the boolean
  `modeB`. Existing units keep their A/B setting on first boot.
- **Manuals** — User Guide and Manual updated to v1.5.0 with the Ultimatic mode;
  manual PDF regenerated.

### Upgrade notes
- Going back to an older firmware will not see a mode chosen in 1.5.0, because
  the old key is no longer updated. The older firmware starts in the A/B mode
  last saved before the upgrade.

---

## [1.4.10] — 2026 — Farnsworth Speed Now Means Overall Speed

### Changed
- **Farnsworth setting is now the overall (effective) speed.** Previously the
  second number set the speed of the gaps, so 20/10 played at about 14.5 WPM
  overall. It now follows the standard definition: characters are sent at
  character speed and the spacing is stretched so the word PARIS takes
  60000 / overall-speed ms. At 20/10 the gap unit is about 218 ms, ten
  repeats of "PARIS" take about 58.5 seconds, and the display shows `20/10`.
  Sources: [W6ZE](https://w6ze.org/btt/BTT054A.pdf),
  [morsecode.world](https://morsecode.world/international/timing/farnsworth.html).
- Changing the character speed with Farnsworth on now keeps the overall speed
  and recalculates the gaps. With Farnsworth off, the gaps follow the character
  speed as before.
- Manuals updated to v1.4.10 with the new wording.

### Upgrade notes
- Saved settings keep their exact timing, but a Farnsworth setting saved by an
  earlier version will now display its true overall speed (an old 20/10 shows
  as 20/14). Re-set Farnsworth if you want a specific overall speed.
- Not yet verified on hardware.

---

## [1.4.9] — 2026 — Fixes: Decoder, Encoder, Docs and Build Config

Cleanup release from a review of the firmware, README, build config and manuals.
The PlatformIO build and a `firmware.bin` have not been verified in this
environment; build with `pio run` before publishing a binary.

### Fixed
- **Underscore (`_`) was sent wrong from files** — the encoder table had the
  wrong pattern; it now sends `..--.-`.
- **`$` could not be decoded from the paddles** — the Morse decode tree held only
  127 entries, too small for the 7-element `...-..-`. It now holds 255 entries,
  and a 16-bit helper (`nextMorsePos`) prevents the position counter wrapping on
  over-long sequences. Longer sequences are discarded.
- **Stale comments** — volume default comment, header feature text and the
  embedded `platformio.ini` block now match the code.

### Changed
- **Build config** — removed the unused OTA library and `ELEGANTOTA` flag
  (OTA was removed in 1.4.0) from `platformio.ini`; deleted the stray
  `firmware/platform.ini/` folder.
- **README** — removed the obsolete OTA option, updated the `platformio.ini`
  block, build-from-source steps and repository structure.
- **Manuals** — User Guide and Manual updated to v1.4.9: default volume 64%
  (firmware default unchanged), volume range 2–100%, edit-mode short-press
  behaviour, and file line-break handling. The manual PDF is regenerated from
  the Word file (the previous PDF was an outdated v1.0 document).

---

## [1.4.8] — 2026 — Bug Fix: CW Timing (Farnsworth and File Playback)

Covers interim builds 1.4.6 and 1.4.7. Timing figures below come from code
analysis and have not yet been bench-verified on hardware.

### Fixed
- **File playback ran slow and choppy** — every dit/dah had two 1-unit gaps after
  it (the playback runner's post-element gap plus a second queued gap), doubling
  intra-character spacing. Character gap was 4 units and word gap 8 units.
  Playback now follows standard timing: 1 unit inside a character, 3 between
  characters, 7 between words. At 20 WPM it previously played at roughly 78% of
  the set speed.
- **Live keyer Farnsworth spacing was non-standard** — the gap after each dit/dah
  used the slow Farnsworth gap speed, stretching spacing inside characters.
  Intra-character gaps now use character speed; character gaps total 3 gap-units
  and word gaps N gap-units. With Farnsworth off, timing is unchanged.
- **Farnsworth setting was cancelled by raising character speed** — the clamp in
  the WPM edit code was inverted. The gap dit length is now kept at or above the
  character dit length.
- Added `effGapDit()` so the `3 * gap - charDit` gap math can never underflow if
  saved settings load with the gap faster than the characters.

### Changed
- **File playback line breaks** — a newline now adds a word gap only if the
  previous character was not already a space or newline. Blank lines, hard-wrapped
  text, `space + newline` and Windows `\r\n` endings no longer add extra pauses.
  Literal spaces are still always honored, so intentional extra spaces still
  lengthen the pause.
---

## [1.4.5] — 2026 — Bug Fix: Iambic Mode A/B Logic

### Fixed
- **Iambic Mode A was incorrectly implemented** — it was latching opposite paddle
  memory during active elements, which is Mode B behavior. Mode A correctly does
  NOT latch any memory during an active element; the opposite paddle must be
  pressed during the inter-element gap to register.
- **Mode B now correctly defined** — latches opposite paddle memory during active
  elements, allowing the next element to be queued early for smoother squeeze keying.
- The original firmware (before v1.4.4) was always behaving as Mode B regardless
  of the mode setting.
---

## [1.4.4] — 2026 — Iambic Mode A/B Selection

### Added
- **Iambic Mode A/B toggle** via GPIO16 long press (1 second)
  - Short press still toggles dit/dah swap as before
  - Header shows A or B after GAP setting
  - Mode saved to NVS and restored on power cycle
- **Header layout improved** — all items now flow left to right with consistent
  9px spacing, no fixed positions that cause overlap or large gaps
- **Straight key switch** now updates header display immediately when toggled

### Changed
- NVS version bumped to 4 — existing units reset to defaults on first boot
- Header shows A/B/SK instead of IAM/SK to fit all items without overlap
---

## [1.4.3] — 2026 — File Playback Improvements and Bug Fixes

### Added
- **Pause/Resume** button on web page — instantly pauses file playback and resumes
  from approximately the same position (within one character)
- **Stop Playback** now truly immediate — flushes element buffer and stops audio instantly
- **Newlines** in text files now insert a word space on the TX line instead of
  being silently ignored — lines of text are clearly separated during playback
- **Playback watchdog** recovers from any stuck playback state automatically

### Fixed
- **Long file playback stopping mid-file** — ring buffer wrap-around bug caused
  incorrect space calculation when fileElemHead wrapped past 255 back to 0, making
  the buffer appear full when it wasn't. Fixed with proper wrap-aware free space
  calculation
- **Inter-element gap conflict** — separated inter-element gap (after keying ends)
  from char/word gap using dedicated fileElemGap flag, preventing double-gap issues
  and occasional playback stalls
- **Resume near end of file** — file is reopened correctly when pausing after
  the file has finished reading but buffer is still draining
---

## [1.4.2] — 2026 — Bug Fix: Iambic Output Logic

### Fixed
- **Iambic DIT/DAH output logic was inverted** — optocoupler circuit is active HIGH
  (GPIO HIGH = LED on = phototransistor conducts = radio keyed) not active LOW as originally coded
  - Added IAMBIC_ACTIVE and IAMBIC_INACTIVE macros for clarity
  - All iambic output writes updated to use correct logic
  - Pins now initialized LOW (inactive) at boot — radio no longer keys on startup
- Removed invalid RTC_CNTL_WDTCONFIG0_REG and esp_efuse calls that caused compile errors on ESP32-S3
- Removed unused esp_efuse includes
---

## [1.4.1] — 2026 — Bug Fix: Morse Decoding for 7, 8, 9

### Fixed
- **Morse decoder** — digits 7, 8, and 9 were mapped to incorrect positions in the binary decode tree
  - 7 (--...) corrected to position 55
  - 8 (---..) corrected to position 59
  - 9 (----.) corrected to position 61
---

## [1.4.0] — 2026 — Iambic Output and Web UI Redesign

### Added
- **Iambic DIT/DAH output** on GPIO40 and GPIO41
  - Active LOW, same optocoupler circuit as existing KEY OUT (GPIO12)
  - Connect to radio's 3.5mm paddle input (tip=DIT, ring=DAH, sleeve=GND)
  - Driven in sync with keyer ISR — exact timing matches actual keying
  - Also driven during file playback — radio transmits CW from practice files
  - Paddle reverse applies to outputs — swapping dit/dah swaps the outputs too
  - Always active — no switch needed, just plug in
- **Dit/Dah swap button** on web page (orange button at top)
  - Shows SWAPPED or NORMAL confirmation after tap
  - GPIO16 button now exclusively handles dit/dah swap (no file control)
- **Improved file list** on web page
  - Filenames shown without .txt extension
  - Underscores displayed as spaces (cq_call.txt → "cq call")
  - Compact Play/Delete buttons per file
  - Works cleanly with 10+ files

### Changed
- GPIO16 button simplified — only toggles dit/dah swap, no file control
- Web page redesigned — Practice Files section prominent, Upload moved to bottom
- File playback drives iambic outputs so radio transmits during practice

### Removed
- OTA firmware update section removed from web page (unreliable on Android)
- ESPAsyncHTTPUpdateServer library dependency removed
---

## [1.3.0] — 2026 — WiFi File Playback

### Added
- **WiFi Access Point** — keyer creates a unique hotspot (K0WLY-XXXX) on boot
  - Connect any phone, tablet, or computer — no password required
  - Browse to http://192.168.4.1 for the file management web page
  - Works on Android, iPhone, Windows, Mac, and Linux
- **Text file playback** — upload .txt files and play them as CW practice
  - Upload files from phone browser — no computer or cables needed
  - Files stored on-board in LittleFS flash filesystem
  - Multiple files supported — tap Play next to any file
  - Delete files from the web page
- **Synchronized TX display** — characters appear as they sound, not ahead
  - Each character displays at the character gap (after all elements played)
  - Word spaces display when the word gap silence plays
  - TX line clears automatically when a new file starts playing
- **GPIO16 button file control** (when files are present):
  - Long press — play/pause current file
  - Short press — cycle to next file (if multiple files loaded)
- **Unique unit ID** — last 4 hex digits of MAC shown on status area
  - Makes it easy to identify which unit is which
  - Matches the WiFi hotspot name (K0WLY-XXXX)
- **AP+STA simultaneous mode** — WiFi hotspot and ESP-NOW peer connection
  work at the same time on the same hardware

### Changed
- WiFi mode changed from WIFI_STA to WIFI_AP_STA
- AP SSID is now unique per unit (K0WLY-XXXX) instead of K0WLY-Keyer
- Status area now shows unit ID above callsign/version
---

## [1.2.3] — 2026 — Audio Only Mode

### Added
- **Audio Only (AO) mode** for head copy delay setting
  - Turn pot to top 10% of range while in DELAY edit mode to enable
  - Header shows `DLY:AO` when active
  - Status area shows `AUDIO ONLY` as the value
  - RX line shows `[Audio Only]` in dim orange when active
  - Incoming CW audio plays normally — only the text display is suppressed
  - Perfect for operators who want pure audible head copy with no visual crutch
---

## [1.2.2] — 2026 — Bug Fix: Received Audio Playback

### Fixed
- **Incoming CW audio** now plays at the sender's speed instead of the receiver's speed
  - Element durations are now transmitted as theoretical values (charDitLen_ms) rather than measured wall-clock time, eliminating timing jitter from the Core 0 loop
  - Inter-element gap on receiver correctly derived from received element duration
  - Audio no longer continues playing on receiver after sender has stopped
- Removed unused `elementStartMs` variable
---

## [1.2.1] — 2026 — Bug Fix: Receive Audio Not Playing

### Fixed
- **Incoming CW audio** was completely silent on receiving unit
  - LEDC channel 1 (remote) was never attached to PIN_SIDETONE — fixed by using LEDC channel 0 (local) for both local and remote playback since they never overlap
  - Inter-element gap between received elements corrected from hardcoded 10ms to proper timing
---

## [1.2.0] — 2026 — Farnsworth Spacing

### Added
- **Firmware version** displayed in status area bottom right (K0WLY v1.2) — `FW_VERSION` define makes future updates a one-line change
- **Farnsworth spacing** — two-speed CW for learning
  - Characters sent at full character speed (fast, sounds like real code)
  - Gaps between characters and words stretched to a slower effective speed
  - Range: 4 WPM minimum effective speed, capped at character speed
  - When equal to character speed, Farnsworth is inactive
  - Header shows `25WPM` when equal, `25/8` (char/farnsworth) when active
- **Two-step WPM edit mode:**
  - Long press on WPM → enters CHAR SPEED step (pot sets character rate)
  - Short press → advances to FARNSWORTH step (pot sets effective rate)
  - Short press again → exits edit mode, saves both values

### Changed
- Internal timing split into `charDitLen_ms` (element duration) and `gapDitLen_ms` (gap duration)
- Word gap threshold uses gap speed dits — automatically scales with Farnsworth setting
- NVS settings version bumped to 3
- Word gap OFF zone widened to bottom 20% of pot travel for easier access
---

## [1.1.0] — 2026 — Word Gap and Display Updates

### Added
- **Word gap spacing** — adjustable word space insertion (OFF or 4–9 dits threshold)
  - GAP parameter added to pot mode cycle: WPM → FREQ → DELAY → VOL → GAP
  - First 20% of pot = OFF, remainder maps to 4–9 dit threshold
  - Spaces inserted on TX and RX lines when silence exceeds threshold
  - Saved to NVS with all other settings
- **K0WLY callsign** now displayed in status area bottom right (scale 2)

### Changed
- Header bar updated: K0WLY callsign removed from header to make room for GAP indicator
- GAP indicator shows GAP:OFF or GAP:4 through GAP:9, highlighted green when active
- NVS settings version bumped to 2
---

## [1.0.0] — 2026 — Initial Release

### Hardware
- LilyGO T-Display S3 AMOLED (ESP32-S3R8) platform
- PC817 optocoupler for radio key line isolation
- Dual 2N4401 NPN transistor audio circuit (speaker + headphones)
- Direct speaker connection — no coupling capacitor required
- 47µF bi-polar coupling cap on headphone output only

### Firmware
- Iambic Mode A keyer state machine on FreeRTOS Core 1
- ESP-NOW peer-to-peer auto-discovery (no router required)
- Two-way CW — transmit elements and decoded characters to peer
- Full Morse code decoding: A-Z, 0-9, punctuation, prosigns
- PARIS timing standard (ITU-R M.1677-1), 5–40 WPM
- Frame buffer display — instantaneous region updates, no glitch
- Single pot with short/long press mode cycling
- Logarithmic volume control via PWM duty cycle
- Head copy delay 0–3 seconds for incoming character display
- Non-volatile settings via ESP32 NVS (Preferences library)
- Straight key mode via SPST hardware switch (GPIO15)
- Paddle reverse via PBNO momentary button (GPIO16)
- Independent sidetone frequency — each unit sets its own pitch
- Radio keying output via PC817 optocoupler (GPIO12)

---

*73 de K0WLY*

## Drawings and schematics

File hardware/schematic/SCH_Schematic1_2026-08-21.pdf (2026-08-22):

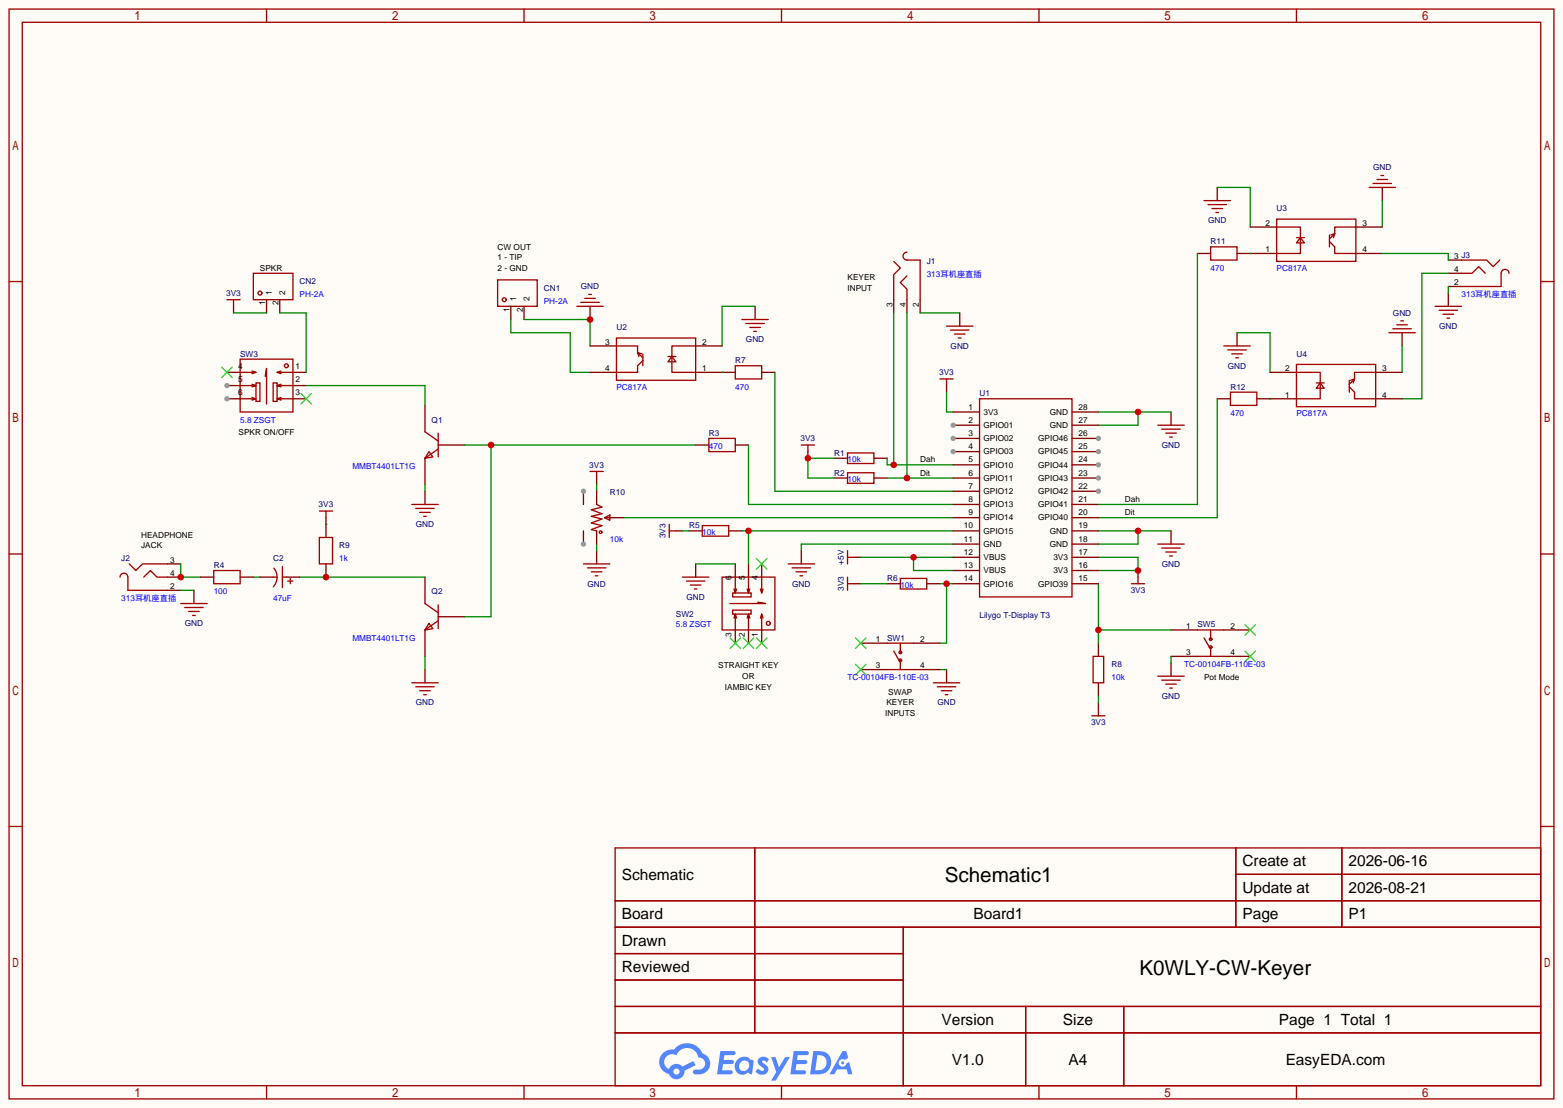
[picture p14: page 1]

Schematic | Schematic1 | Create at | 2026-06-16

Update at | 2026-08-21

Board | Board1 | Page | P1
Drawn | | K0WLY-CW-Keyer
Reviewed

Version | Size | Page 1 Total 1

V1.0 | A4 | EasyEDA.com

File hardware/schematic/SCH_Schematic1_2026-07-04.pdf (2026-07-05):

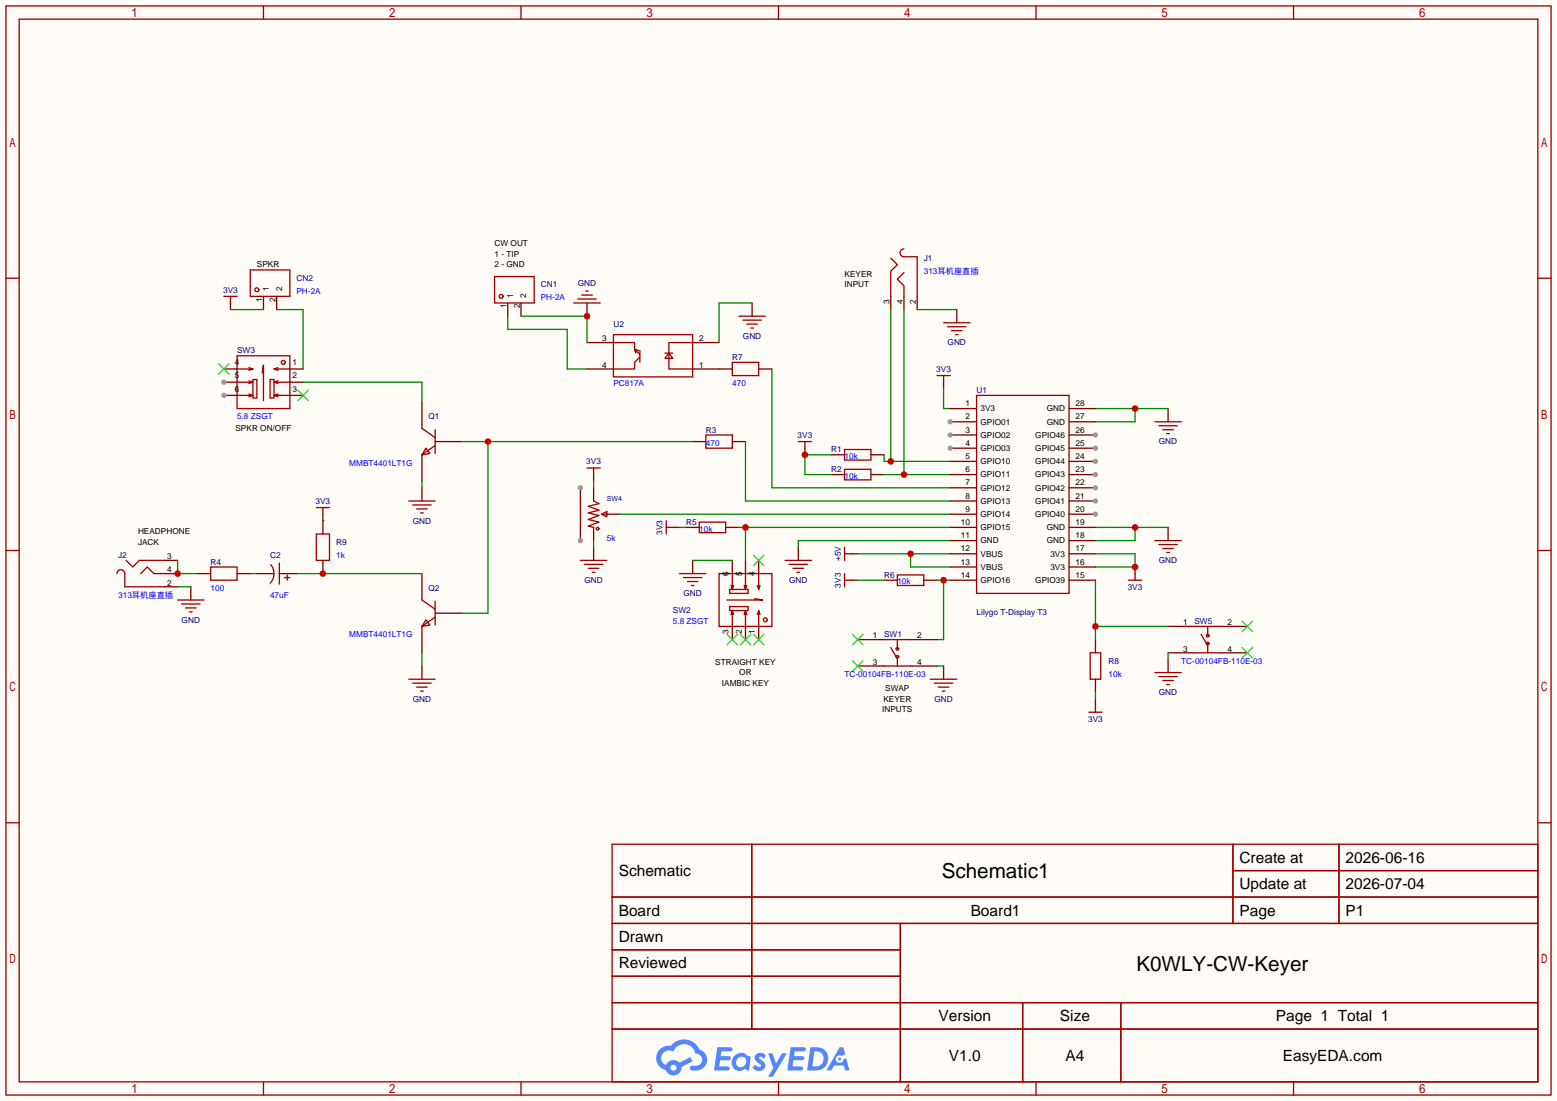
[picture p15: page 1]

Schematic | Schematic1 | Create at | 2026-06-16

Update at | 2026-07-04

Board | Board1 | Page | P1
Drawn | | K0WLY-CW-Keyer
Reviewed

Version | Size | Page 1 Total 1

V1.0 | A4 | EasyEDA.com

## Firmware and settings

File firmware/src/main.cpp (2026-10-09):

// ============================================================================
//  ESP32-S3 Two-Way CW Keyer — LilyGO T-Display S3 AMOLED 1.91" (RM67162)
//  K0WLY build  —  PlatformIO / Arduino framework
//  Version 1.5.0
//
//  Copyright © 2026 K0WLY (Carl Cowley)
//  Saratoga Springs, Utah — Grid Square DN40
//
//  Licensed under the CERN Open Hardware Licence Version 2 - Weakly Reciprocal
//  (CERN-OHL-W v2). You may redistribute and modify this work under the terms
//  of the CERN-OHL-W v2 (https://ohwr.org/cern_ohl_w_v2.txt).
//  Attribution to K0WLY must be retained on all copies and derivatives.
//
//  FEATURES:
//    - Iambic Mode A, Iambic Mode B or Ultimatic keyer with sidetone (or straight key via GPIO15 switch)
//    - ESP-NOW peer-to-peer WiFi (auto-discovery, no router needed)
//    - Two-way CW: outgoing keyed locally, transmitted to peer
//    - Incoming CW replayed with sender's frequency + shown on screen
//    - Head copy delay: incoming chars display delayed 0-3s after receipt
//    - Audio Only mode: incoming audio plays but RX text suppressed
//    - Farnsworth spacing: character speed + overall (effective) speed, e.g. 20/10
//    - Word gap spacing: automatic space detection
//    - File playback: send text file via phone web browser → plays in CW
//    - WiFi AP: connect phone to the K0WLY-XXXX hotspot (XXXX = unit ID), upload/manage files
//    - Single pot cycles through WPM / FREQ / DELAY / VOL / GAP modes
//    - Display: header | TX scrolling line | RX scrolling line | status
//
//  platformio.ini (firmware/platformio.ini in the repository):
//  ─────────────────────────────────────────────────────────────
//  [platformio]
//  boards_dir = ./boards
//
//  [env:t_display_s3_amoled]
//  platform = espressif32
//  board = lilygo-t-amoled
//  framework = arduino
//  monitor_speed = 115200
//  board_build.partitions = partitions.csv
//  board_build.filesystem = littlefs
//  build_flags =
//      -DBOARD_HAS_PSRAM
//      -DARDUINO_USB_CDC_ON_BOOT=1
//      -DASYNCWEBSERVER_REGEX=0
//  lib_deps =
//      https://github.com/Xinyuan-LilyGO/LilyGo-AMOLED-Series
//      https://github.com/moononournation/Arduino_GFX#v1.4.7
//      https://github.com/ESP32Async/AsyncTCP
//      https://github.com/ESP32Async/ESPAsyncWebServer
//  ─────────────────────────────────────────────────────────────
//
//  GPIO PIN ASSIGNMENTS (1.91" AMOLED — reserved: 2,3,5,6,7,9,17,18,21,38,47,48)
//  ┌──────────────────┬────────┬─────────────────────────────────────────┐
//  │ Function         │ GPIO   │ Notes                                   │
//  ├──────────────────┼────────┼─────────────────────────────────────────┤
//  │ DIT paddle       │ GPIO11 │ Active LOW, ext 10kΩ pull-up            │
//  │ DAH paddle       │ GPIO10 │ Active LOW, ext 10kΩ pull-up            │
//  │ KEY OUT          │ GPIO12 │ HIGH=keyed, drives PC817 optocoupler    │
//  │ SIDETONE         │ GPIO13 │ PWM → 470Ω → 2N4401 → 8Ω speaker       │
//  │ POT (ADC)        │ GPIO14 │ Wiper of 10kΩ pot (WPM/FREQ/DLY/VOL)  │
//  │ KEY MODE         │ GPIO15 │ LOW=straight key, open=iambic (pullup) │
//  │ PADDLE REVERSE   │ GPIO16 │ Active LOW momentary button             │
//  │ POT MODE SELECT  │ GPIO39 │ Active LOW momentary button             │
//  └──────────────────┴────────┴─────────────────────────────────────────┘
// ============================================================================

#include <Arduino.h>
#include <LilyGo_AMOLED.h>
#include <WiFi.h>
#include <esp_now.h>
#include <esp_wifi.h>
#include <Preferences.h>
#include <LittleFS.h>
#include <AsyncTCP.h>
#include <ESPAsyncWebServer.h>
#include "driver/gpio.h"
#include "rom/gpio.h"

Preferences prefs;

// Firmware version — update this whenever code changes
#define FW_VERSION "v1.5.0"

// WiFi AP settings for file upload
#define AP_SSID     "K0WLY-Keyer"
#define AP_PASSWORD ""           // open network — no password
#define AP_IP       "192.168.4.1"

// Unit ID — last 4 hex digits of MAC, set during WiFi init
static char unitID[8] = "????";
static char apSSID[24] = "K0WLY-????";  // set during init

// Web server on port 80
AsyncWebServer webServer(80);

// File playback state
#define MAX_FILES       20
#define MAX_FILENAME    32
#define FILE_SEND_DELAY 5   // ms between characters during playback check

static char     fileList[MAX_FILES][MAX_FILENAME];
static int      fileCount        = 0;
static int      currentFileIdx   = 0;
static bool     filePlayActive   = false;
static bool     filePlayPaused   = false;
static File     playFile;
static bool     filesAvailable   = false;
volatile bool   fileKeying       = false;
static bool     fileInGap        = false;
static bool     fileElemGap      = false;
static uint32_t fileGapEndMs     = 0;
static uint32_t fileElemGapEndMs = 0;
static size_t   filePlayedPos    = 0;  // file position of last character that started playing
static bool     fileLastWasSpace = true; // true if last queued char was a space/newline (collapses line breaks only)

// ── Pin definitions ──────────────────────────────────────────────────────────
#define PIN_DIT         11
#define PIN_DAH         10
#define PIN_KEY_OUT     12
#define PIN_SIDETONE    13
#define PIN_POT         14
#define PIN_REVERSE     16
#define PIN_MODE_BTN    39
#define PIN_KEY_MODE    15   // LOW = straight key, HIGH (default) = iambic
#define PIN_IAMBIC_DIT  40   // Iambic DIT output to radio paddle input
#define PIN_IAMBIC_DAH  41   // Iambic DAH output to radio paddle input
// Optocoupler is active HIGH (HIGH = LED on = phototransistor conducts = radio keyed)
#define IAMBIC_ACTIVE   HIGH
#define IAMBIC_INACTIVE LOW

// ── LEDC ─────────────────────────────────────────────────────────────────────
#define LEDC_CHANNEL_LOCAL  0
#define LEDC_CHANNEL_REMOTE 1
#define LEDC_RES_BITS       8
// SIDETONE_DUTY is now a variable (10-255) controlled by pot VOL mode
volatile uint8_t sidetone_duty = 128;  // default duty 128 — shows as 64% (the VOL scale maps duty 200 = 100%)

// ── Keyer parameters ─────────────────────────────────────────────────────────
#define WPM_MIN         5
#define WPM_MAX         40
#define FREQ_MIN        400
#define FREQ_MAX        900
#define DELAY_MIN_MS    0
#define DELAY_MAX_MS    3000
#define DELAY_AO_MODE   0xFFFFFFFF  // sentinel value meaning Audio Only mode
#define GAP_MIN         0    // 0 = off
#define GAP_MAX         9    // max word gap threshold in dits

// ── Pot modes ────────────────────────────────────────────────────────────────
typedef enum { POT_WPM = 0, POT_FREQ, POT_DELAY, POT_VOL, POT_GAP, POT_MODE_COUNT } PotMode;
volatile PotMode potMode = POT_WPM;

// Pot pickup mode — prevents value jumping when switching modes
// All modes start picked up; pickup positions initialized in setup() from actual pot reading
int  potPickupRaw[POT_MODE_COUNT] = {2047, 2047, 2047, 2047, 2047};
bool potPickedUp[POT_MODE_COUNT]  = {true, true, true, true, true};
#define PICKUP_DEADBAND     300

// Edit mode — pot only changes values when in edit mode (long press to enter)
bool potEditMode = false;
uint8_t wpmEditStep = 0;  // 0=char speed, 1=Farnsworth overall speed (only used when potMode==POT_WPM)

// Long press detection
#define LONG_PRESS_MS       1000

// ── Runtime state ─────────────────────────────────────────────────────────────
volatile uint32_t charDitLen_ms   = 60;    // character speed dit length (20 WPM default)
volatile uint32_t gapDitLen_ms    = 60;    // Farnsworth gap unit length in ms (= char dit when Farnsworth is off)
volatile uint32_t farnTargetWPM   = 20;    // overall (effective) speed the gap unit is derived from
volatile uint32_t localFreq       = 700;   // local sidetone Hz — each unit sets its own
volatile uint32_t headCopyDelayMs = 0;     // incoming char display delay
volatile uint8_t  wordGapDits     = 0;     // 0=off, 4-9 = word gap threshold in dits
volatile bool     paddleReverse   = false;
volatile bool     straightKey     = false; // false = iambic, true = straight key
// Paddle keyer mode — cycled by GPIO16 long press, saved to NVS
#define KEYER_MODE_A        0   // Iambic A: squeeze alternates, no memory during element
#define KEYER_MODE_B        1   // Iambic B: squeeze alternates, opposite paddle latched during element
#define KEYER_MODE_ULTIMATIC 2  // Ultimatic: on squeeze, last-pressed paddle wins and repeats
#define KEYER_MODE_COUNT    3
volatile uint8_t  keyerMode       = KEYER_MODE_A;
volatile bool     lastPaddleDah   = false; // Ultimatic: most recently pressed paddle was DAH

// Convenience: character WPM and Farnsworth effective WPM
static inline uint32_t charWPM() { return 1200 / charDitLen_ms; }
// Farnsworth: characters are sent at character speed; only the gaps stretch so
// that the word PARIS (31 character units + 19 gap units) takes 60000/overall ms.
// Gap unit = (60000/overall - 31*charDit) / 19. Gaps are 3 and 7 gap units.
static inline uint32_t farnGapDitFor(uint32_t overallWPM, uint32_t charDit) {
    if (overallWPM < 1) overallWPM = 1;
    uint32_t total = 60000 / overallWPM;
    uint32_t chars = 31 * charDit;
    if (overallWPM >= 1200 / charDit || total <= chars + 19 * charDit) return charDit;   // at/above char speed: no Farnsworth
    return (total - chars + 9) / 19;                          // rounded
}
// Overall (effective) speed implied by the current dit lengths.
static inline uint32_t farnWPM() {
    uint32_t g = gapDitLen_ms, c = charDitLen_ms;
    if (g <= c) return 1200 / c;
    return (60000 + (31 * c + 19 * g) / 2) / (31 * c + 19 * g);   // rounded
}
// Effective gap dit length: never shorter than the character dit. Guards the
// (3 * gap - char) character-gap math against unsigned underflow.
static inline uint32_t effGapDit() { uint32_t g = gapDitLen_ms, c = charDitLen_ms; return g > c ? g : c; }

// ── Keyer state machine ───────────────────────────────────────────────────────
typedef enum {
    KEYER_IDLE,
    KEYER_DIT, KEYER_DIT_GAP,
    KEYER_DAH, KEYER_DAH_GAP,
    KEYER_CHAR_GAP, KEYER_WORD_GAP
} KeyerState;

volatile KeyerState keyerState   = KEYER_IDLE;
volatile uint32_t   elementTimer = 0;
volatile bool       ditMemory    = false;
volatile bool       dahMemory    = false;

// ── Morse decoder ─────────────────────────────────────────────────────────────
// Binary tree: dit = pos*2+1, dah = pos*2+2
// 255 entries: sequences of up to 7 elements (7-element '$' is at index 136), covering
// letters, numbers, punctuation, and prosigns. Longer sequences are discarded.
// Prosigns: + = AR (end of message), = BT (break/paragraph), ~ = SK (end of contact)
static const char morseTree[] = {
    ' ','E','T','I','A','N','M','S','U','R',  // 0-9
    'W','D','K','G','O','H','V','F',' ','L',  // 10-19
    ' ','P','J','B','X','C','Y','Z','Q',' ',  // 20-29
    ' ','5','4',' ','3',' ',' ',' ','2','&',  // 30-39  (&=AS)
    ' ','+',' ',' ',' ',' ','1','6','=','/',  // 40-49  (+=AR, ==BT)
    ' ',' ',' ','(',' ','7',' ',' ',' ','8',  // 50-59
    ' ','9','0',' ',' ',' ',' ',' ','~',' ',  // 60-69  (~=SK at pos 68)
    ' ',' ',' ',' ',' ','?','_',' ',' ',' ',  // 70-79
    ' ','"',' ',' ','.',' ',' ',' ',' ','@',  // 80-89
    ' ',' ',' ','\'',' ',' ','-',' ',' ',' ', // 90-99
    ' ',' ',' ',' ',' ',';','!',' ',')',' ',  // 100-109
    ' ',' ',' ',' ',',',' ',' ',' ',' ',':',  // 110-119
    ' ',' ',' ',' ',' ',' ',' ',' ',' ',' ',  // 120-129
    ' ',' ',' ',' ',' ',' ','$',' ',' ',' ',  // 130-139
    ' ',' ',' ',' ',' ',' ',' ',' ',' ',' ',  // 140-149
    ' ',' ',' ',' ',' ',' ',' ',' ',' ',' ',  // 150-159
    ' ',' ',' ',' ',' ',' ',' ',' ',' ',' ',  // 160-169
    ' ',' ',' ',' ',' ',' ',' ',' ',' ',' ',  // 170-179
    ' ',' ',' ',' ',' ',' ',' ',' ',' ',' ',  // 180-189
    ' ',' ',' ',' ',' ',' ',' ',' ',' ',' ',  // 190-199
    ' ',' ',' ',' ',' ',' ',' ',' ',' ',' ',  // 200-209
    ' ',' ',' ',' ',' ',' ',' ',' ',' ',' ',  // 210-219
    ' ',' ',' ',' ',' ',' ',' ',' ',' ',' ',  // 220-229
    ' ',' ',' ',' ',' ',' ',' ',' ',' ',' ',  // 230-239
    ' ',' ',' ',' ',' ',' ',' ',' ',' ',' ',  // 240-249
    ' ',' ',' ',' ',' '                       // 250-254
};
volatile uint8_t morsePos = 0;

// Advance the decoder position by one element. The arithmetic is done in 16 bits and
// range-checked BEFORE narrowing to uint8_t: with a 255-entry table, pos*2+2 can exceed
// 255 and would otherwise wrap around and decode as the wrong character.
// Returns 0 (restart) when the sequence is longer than the table supports.
static inline uint8_t nextMorsePos(uint8_t pos, bool isDah) {
    uint16_t n = (uint16_t)pos * 2 + (isDah ? 2 : 1);
    return (n >= sizeof(morseTree)) ? 0 : (uint8_t)n;
}
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
void loop() {
    uint32_t now = millis();

    // ── Paddle reverse button ────────────────────────────────────────────────
    // ── Paddle reverse button (GPIO16) — short=dit/dah swap, long=Mode A/B/U ──
    if (now - lastRevCheck >= 50) {
        lastRevCheck = now;
        static bool lastRevBtn = HIGH;
        static uint32_t revPressedAt = 0;
        static bool revLongFired = false;
        bool cur = digitalRead(PIN_REVERSE);

        if (lastRevBtn == HIGH && cur == LOW) {
            revPressedAt = now;
            revLongFired = false;
        }

        if (cur == LOW && !revLongFired) {
            if (now - revPressedAt >= LONG_PRESS_MS) {
                revLongFired = true;
                keyerMode = (keyerMode + 1) % KEYER_MODE_COUNT;  // A → B → Ultimatic → A
                drawHeader();
                saveSettings();
                drawHeader();
            }
        }

        if (lastRevBtn == LOW && cur == HIGH) {
            if (!revLongFired) {
                paddleReverse = !paddleReverse;
            }
        }

        lastRevBtn = cur;
    }

    // ── Straight key / iambic toggle (GPIO15) ───────────────────────────────
    // Uncomment when SK switch is physically wired to GPIO15
    // ── Straight key / iambic mode switch (GPIO15) ───────────────────────────
    {
        static bool lastKeyMode = HIGH;
        bool cur = digitalRead(PIN_KEY_MODE);
        if (cur != lastKeyMode) {
            lastKeyMode = cur;
            straightKey = (cur == LOW);
            drawHeader();
        }
    }

    // ── Pot mode button (short press = next mode, long press = edit mode) ───────
    if (now - lastModeCheck >= 20) {  // 20ms debounce poll
        lastModeCheck = now;
        static bool    lastModeBtn   = HIGH;
        static uint32_t btnPressedAt = 0;
        static bool    longFired     = false;

        bool cur = digitalRead(PIN_MODE_BTN);

        if (lastModeBtn == HIGH && cur == LOW) {
            // Button just pressed — start timing
            btnPressedAt = now;
            longFired    = false;
        }

        if (cur == LOW && !longFired) {
            // Button held — check for long press
            if (now - btnPressedAt >= LONG_PRESS_MS) {
                longFired    = true;
                potEditMode  = !potEditMode;
                if (potEditMode) {
                    // Entering edit mode — sync pickup to current pot position
                    potPickupRaw[potMode] = readPotSmoothed();
                    potPickedUp[potMode]  = true;
                }
                drawRXLine();   // update AO indicator if delay mode changed
                drawStatusArea();
                drawHeader();
            }
        }

        if (lastModeBtn == LOW && cur == HIGH) {
            // Button released
            if (!longFired) {
                if (potEditMode && potMode == POT_WPM && wpmEditStep == 0) {
                    // Short press in WPM step 1 — advance to Farnsworth step
                    wpmEditStep = 1;
                    potPickupRaw[potMode] = readPotSmoothed();
                    potPickedUp[potMode]  = true;
                    drawStatusArea();
                    drawHeader();
                } else {
                    // Short press — exit edit mode, cycle to next mode
                    potEditMode  = false;
                    wpmEditStep  = 0;
                    potPickupRaw[potMode] = readPotSmoothed();
                    potMode = (PotMode)((potMode + 1) % POT_MODE_COUNT);
                    potPickupRaw[potMode] = readPotSmoothed();
                    potPickedUp[potMode]  = true;
                    drawRXLine();   // update AO indicator if delay mode changed
                    drawStatusArea();
                    drawHeader();
                }
            }
        }

        lastModeBtn = cur;
    }

    // ── Pot reading (only active in edit mode) ────────────────────────────────
    if (potEditMode && now - lastPotUpdate >= 100) {
        lastPotUpdate = now;
        bool changed = false;
        int rawNow = readPotSmoothed();

        switch (potMode) {
            case POT_WPM: {
                if (wpmEditStep == 0) {
                    // Step 1: character speed
                    uint32_t wpm = WPM_MIN + (uint32_t)((rawNow / 4095.0f) * (WPM_MAX - WPM_MIN));
                    if (wpm < 1) wpm = 1;
                    uint32_t newDit = 1200 / wpm;
                    if (newDit != charDitLen_ms) {
                        bool farnWasOff = (gapDitLen_ms <= charDitLen_ms);
                        charDitLen_ms = newDit;
                        if (farnWasOff) {
                            // Farnsworth off: gaps follow the character speed
                            gapDitLen_ms  = charDitLen_ms;
                            farnTargetWPM = charWPM();
                        } else {
                            // Farnsworth on: keep the overall speed, re-derive the gap unit
                            gapDitLen_ms = farnGapDitFor(farnTargetWPM, charDitLen_ms);
                        }
                        changed = true;
                    }
                } else {
                    // Step 2: Farnsworth overall (effective) speed (4 WPM min, capped at char speed)
                    uint32_t farnMax = charWPM();
                    uint32_t farnMin = 4;
                    if (farnMax < farnMin) farnMax = farnMin;
                    uint32_t wpm = farnMin + (uint32_t)((rawNow / 4095.0f) * (farnMax - farnMin));
                    if (wpm < farnMin) wpm = farnMin;
                    if (wpm > farnMax) wpm = farnMax;
                    uint32_t newGapDit = farnGapDitFor(wpm, charDitLen_ms);
                    if (newGapDit != gapDitLen_ms) { gapDitLen_ms = newGapDit; farnTargetWPM = wpm; changed = true; }
                }
                break;
            }
            case POT_FREQ: {
                uint32_t freq = FREQ_MIN + (uint32_t)((rawNow / 4095.0f) * (FREQ_MAX - FREQ_MIN));
                if (freq != localFreq) {
                    localFreq = freq;
                    // keyer task will pick up new localFreq on next element start
                    changed = true;
                }
                break;
            }
            case POT_DELAY: {
                uint32_t del = readDelay();
                if (del != headCopyDelayMs) {
                    headCopyDelayMs = del;
                    changed = true;
                    drawRXLine();
                }
                break;
            }
            case POT_VOL: {
                uint8_t vol = readVol();
                if (vol != sidetone_duty) { sidetone_duty = vol; changed = true; }
                break;
            }
            case POT_GAP: {
                uint8_t gap = readGap();
                if (gap != wordGapDits) { wordGapDits = gap; changed = true; }
                break;
            }
            default: break;
        }
        potPickupRaw[potMode] = rawNow;

        if (changed) {
            saveSettings();   // save to NVS as value changes
            drawStatusArea();
            drawHeader();
        }
    }

    // ── Header refresh (peer status may change) ───────────────────────────────
    if (now - lastHeaderUpdate >= 500) {
        lastHeaderUpdate = now;
        static bool lastFilePlay = false;
        static bool lastFilePause = false;
        bool needRedraw = false;
        if (peerFound != lastPeerFound) { lastPeerFound = peerFound; needRedraw = true; }
        if (filePlayActive != lastFilePlay || filePlayPaused != lastFilePause) {
            lastFilePlay  = filePlayActive;
            lastFilePause = filePlayPaused;
            needRedraw = true;
        }
        if (needRedraw) {
            drawHeader();
            drawStatusArea();
        }
    }

    // ── Discovery broadcast ───────────────────────────────────────────────────
    if (!peerFound && now - lastDiscovery >= 2000) {
        lastDiscovery = now;
        CWPacket pkt;
        memset(&pkt, 0, sizeof(pkt));
        pkt.type = PKT_DISCOVER;
        esp_now_send(broadcastAddr, (uint8_t*)&pkt, sizeof(pkt));
        Serial.println("Broadcasting discover...");
    }

    // ── Detect keyer element transitions for transmission ────────────────────
    KeyerState curState = keyerState;

    // Element start: IDLE/GAP → DIT or DAH
    if ((lastKeyerState == KEYER_IDLE || lastKeyerState == KEYER_DIT_GAP || lastKeyerState == KEYER_DAH_GAP)
        && (curState == KEYER_DIT || curState == KEYER_DAH)) {
        // Nothing needed here — duration calculated from charDitLen_ms
    }
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

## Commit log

2026-07-05 Initial release v1.0.0
    [BOM_Board1_Schematic1_2026-07-04.xlsx, PickAndPlace_PCB1_2026_07_04.xlsx]
2026-07-15 Fix K0WLY version display size in status area
    [main.cpp]
2026-07-16 Fix header parameter colors - show full color when selected
    [main.cpp]
2026-07-21 Fix audio playback of incoming CW elements on receiving unit. Bump version to v1.2.1
    [main.cpp]
2026-07-22 Fix incoming CW audio playback speed to match sender
    [main.cpp]
2026-07-31 Add Audio Only mode to head copy delay — audio plays without RX text display
2026-07-31 Fix Audio Only text color - dim orange instead of invisible darkgray
    [main.cpp]
2026-08-21 Add firmware flashing instructions, OTA support, move PlatformIO to repo, add PCB photos
    [partitions.csv]
2026-08-22 v1.4.0 - Add iambic DIT/DAH output, redesign web UI, remove OTA
    [main.cpp]
2026-08-22 v1.4.0 - Add iambic output, redesign web UI, update manual
    [main.cpp]
2026-08-22 Rev. 02 of the PCB files (Gerbers) and Pick and Place file for Firmware V1.4.0
    [BOM_Board1_Schematic1_2026-08-21.xlsx, PickAndPlace_PCB1_2026_08_21.xlsx]
2026-08-22 Add 3D printable enclosure files
    [3D_PCB1_2026-08-07.SLDPRT, EnclosureBottom.SLDPRT, EnclosureBottom.STL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]
2026-08-22 Fix Morse decoding for digits 7, 8, 9 - incorrect tree positions
    [main.cpp]
2026-08-29 v1.4.2 - Fix iambic output logic - active HIGH not active LOW
    [main.cpp]
2026-08-29 Rev 03 PCB - Fix GPIO41 trace incorrectly connected to GND pour
    [PickAndPlace_PCB1_2026_08_28.xlsx]
2026-09-10 v1.4.4 - Add Iambic Mode A/B, fix header layout, update manuals
    [main.cpp]
2026-09-11 v1.4.4 - corrected morseTreeposition so <SK> or ~ is at proper location.
    [main.cpp]
2026-09-11 v1.4.5 - Fix Iambic Mode A/B logic
    [main.cpp]
2026-10-08 Files of latest PCB and parts.
2026-10-09 Release v1.4.8: standard CW timing for Farnsworth and file playback
    - File playback: remove doubled intra-character gap; character gap now
    3 gap-units and word gap 7 gap-units (was 4 and 8)
    - Live keyer: intra-character gap at character speed, character gap
    3 * gap - charDit, so Farnsworth spacing is standard
    - Fix inverted gap/char clamp in WPM edit that cancelled Farnsworth
    - Add effGapDit() guard against unsigned underflow in gap math
    - File playback: newlines only add a word gap after a non-space character;
    literal spaces still honored
    - Add CHANGELOG entry for 1.4.8 (covers interim 1.4.6 and 1.4.7)
    Timing figures come from code analysis; not yet bench-verified on hardware.
    Co-Au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
    [main.cpp]
2026-10-09 Fix underscore encoding and $ decoding; refresh stale comments (v1.4.9)
    Claude-Session: https://claude.ai/code/session_01FgUwPeQZb4nSMdptaYUNCX
    [main.cpp]
2026-10-13 Web page: skip 39 WPM when stepping character speed
    39 and 40 WPM both give a 30 ms dit, which the device reports as 40, so
    the page could never reach 39. "−" from 40 snapped back to 40 (and with
    Farnsworth off, turned Farnsworth on at 39); "+" from 38 jumped to 40.
    The speed tile now steps 38 <-> 40.
2026-10-13 /set: ignore values that aren't plain numbers
    Non-numeric or negative values were read as 0, which meant something
    different for each setting: vol=abc dropped the volume to its minimum,
    farn=abc turned Farnsworth on at 4 WPM, kmode=abc switched to Iambic A.
    Values like 12abc or 1.5 were accepted as 12 and 1. A request with no
    usable values still left pot edit mode and wrote to NVS.
    Only plain decimal digits (up to 9) are accepted now; anything else is
    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
2026-10-13 Web page: label paddle buttons Dit-Dah / Dah-Dit

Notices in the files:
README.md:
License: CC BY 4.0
